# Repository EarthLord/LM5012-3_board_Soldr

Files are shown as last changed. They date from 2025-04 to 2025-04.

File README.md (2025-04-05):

# LM5012/LM5013 regulator board made for Sodlr with KiCad

## Requirements of the board from Soldr
1. Ideas that are fun and satisfying to build
2. Not trash-bound – ideally something you'd enjoy using or keeping on your desk/shelf
3. Low production cost – target is $1–3 per unit
4. Beginner-friendly – something accessible, even if it’s your first time soldering

## Specs of the board
1. 12V to 100V input to 5V output
  1. Can be down to 6V input if voltage divider for under-voltage lockout is tweaked
  2. 5V output can change also if feedback voltage divider is changed
2. 2.5A maximum output with LM5012 and 3.5A maximum output with LM5013
3. Sub 100uA current drawn at no load
4. BoM and PCB would come to around 2 to 3 USD depending on the chip used and quantity. 

### Soldering experience
The design is made such that different component sizes and soldering gun heat levels are utilized.

1. Both through hole and surface mount components
2. All surface mount components are with larger leads for hand soldering
3. Size varies from a large inductor to 0402 capacitors and resistors for surface mount components
4. Also experience of soldering an exposed pad from the back side for the regulator

## Documentation
The design is documented in the [schematic](output/schematic.pdf). The gerber files are in the gerber folder. The renders of the board are below.
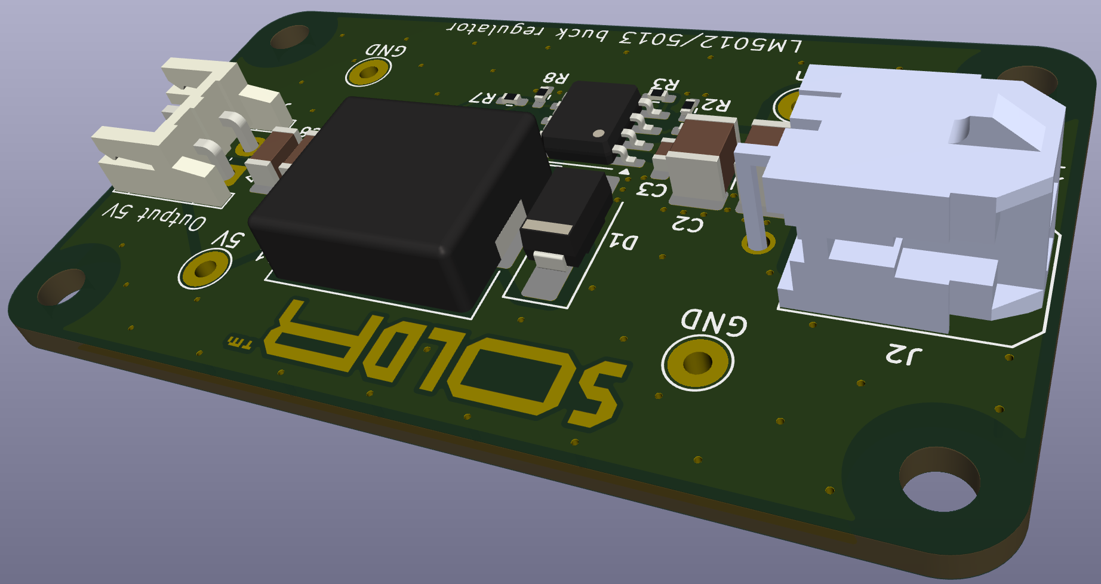
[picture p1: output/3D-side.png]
side

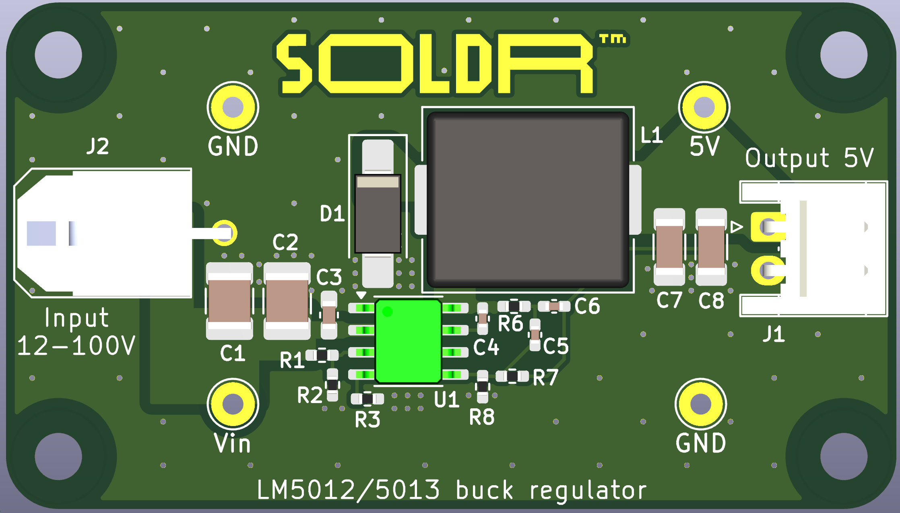
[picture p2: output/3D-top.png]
top

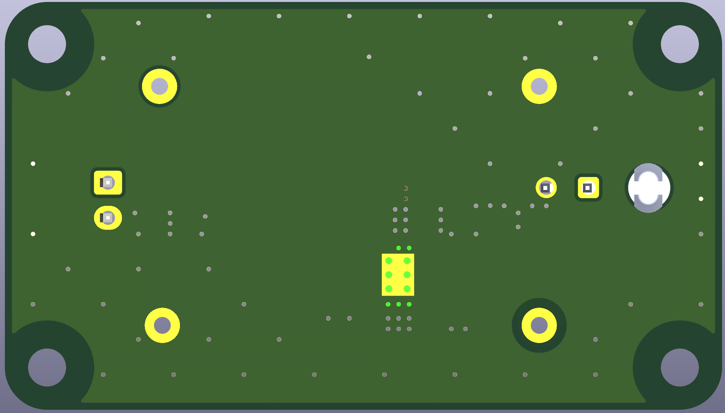
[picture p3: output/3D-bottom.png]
bottom


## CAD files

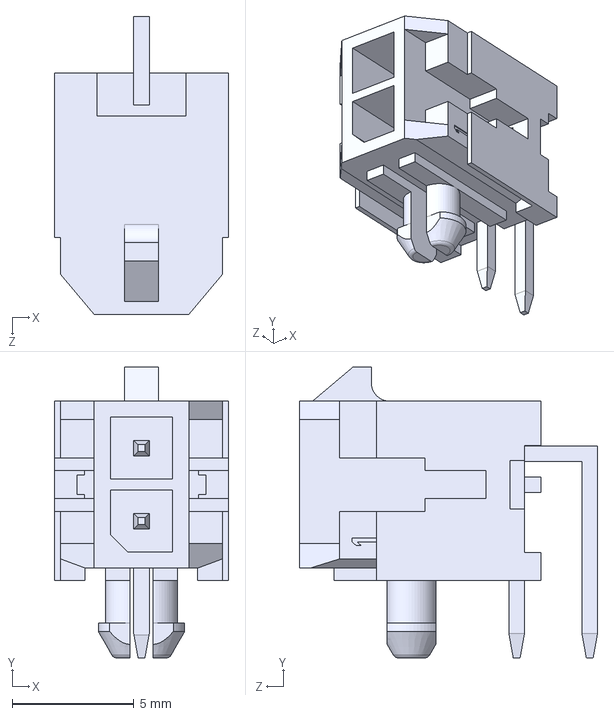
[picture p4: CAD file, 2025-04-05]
3D_models/430450200--3DModel-STEP-56544.STEP
7.15 x 11.9 x 12.2 mm

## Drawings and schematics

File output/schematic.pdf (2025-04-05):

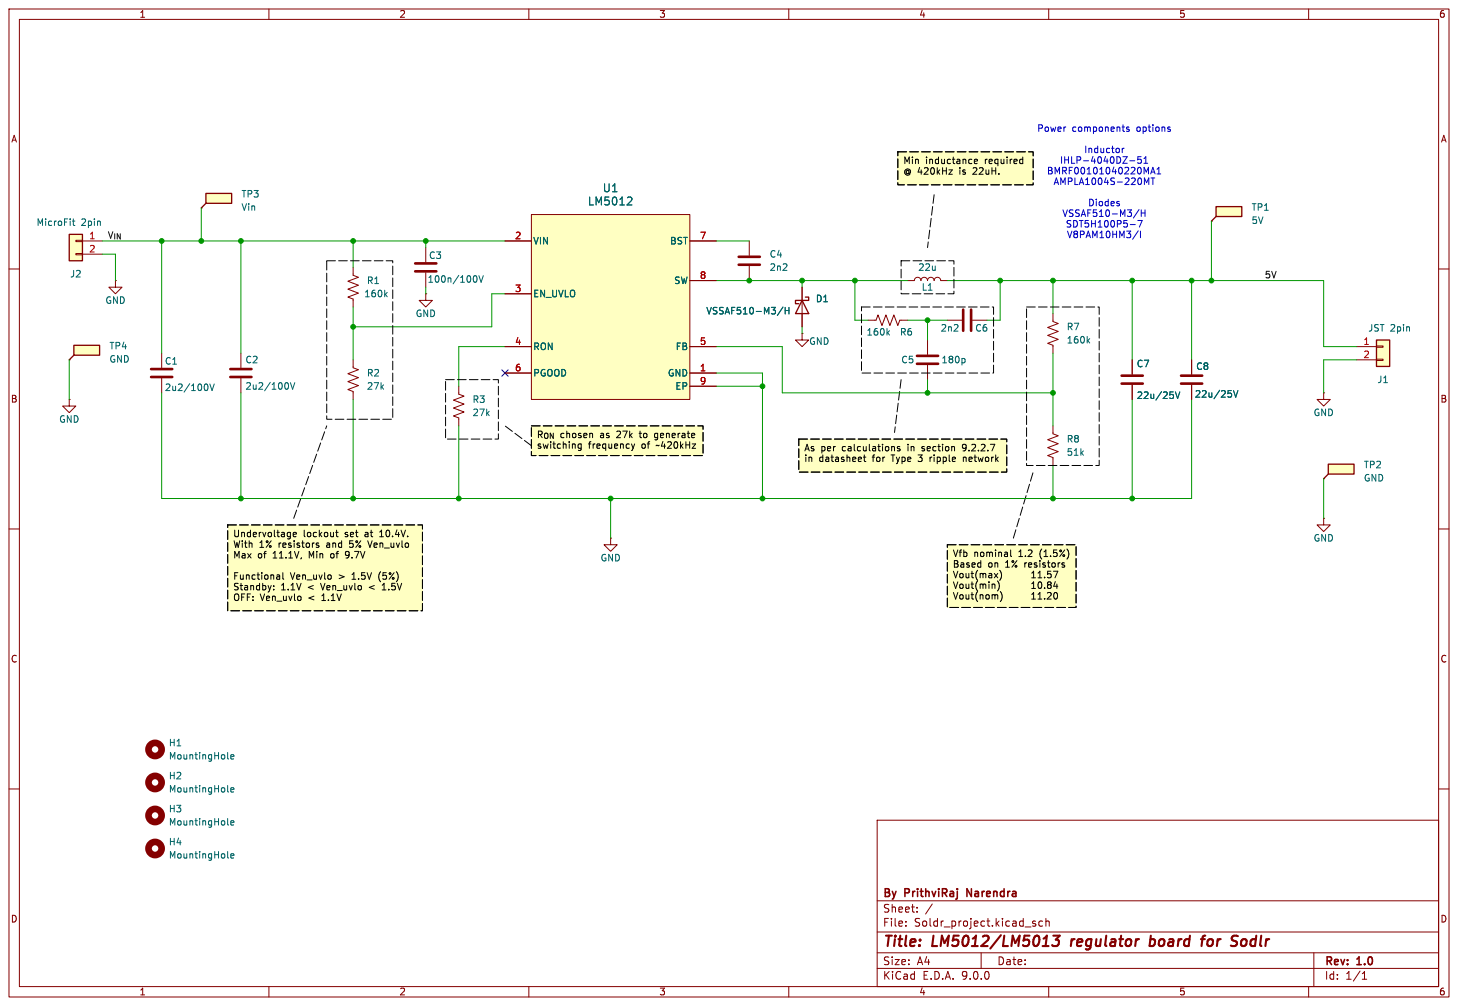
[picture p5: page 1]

160k H4 MountingHole H1 MountingHole H3 MountingHole H2 MountingHole

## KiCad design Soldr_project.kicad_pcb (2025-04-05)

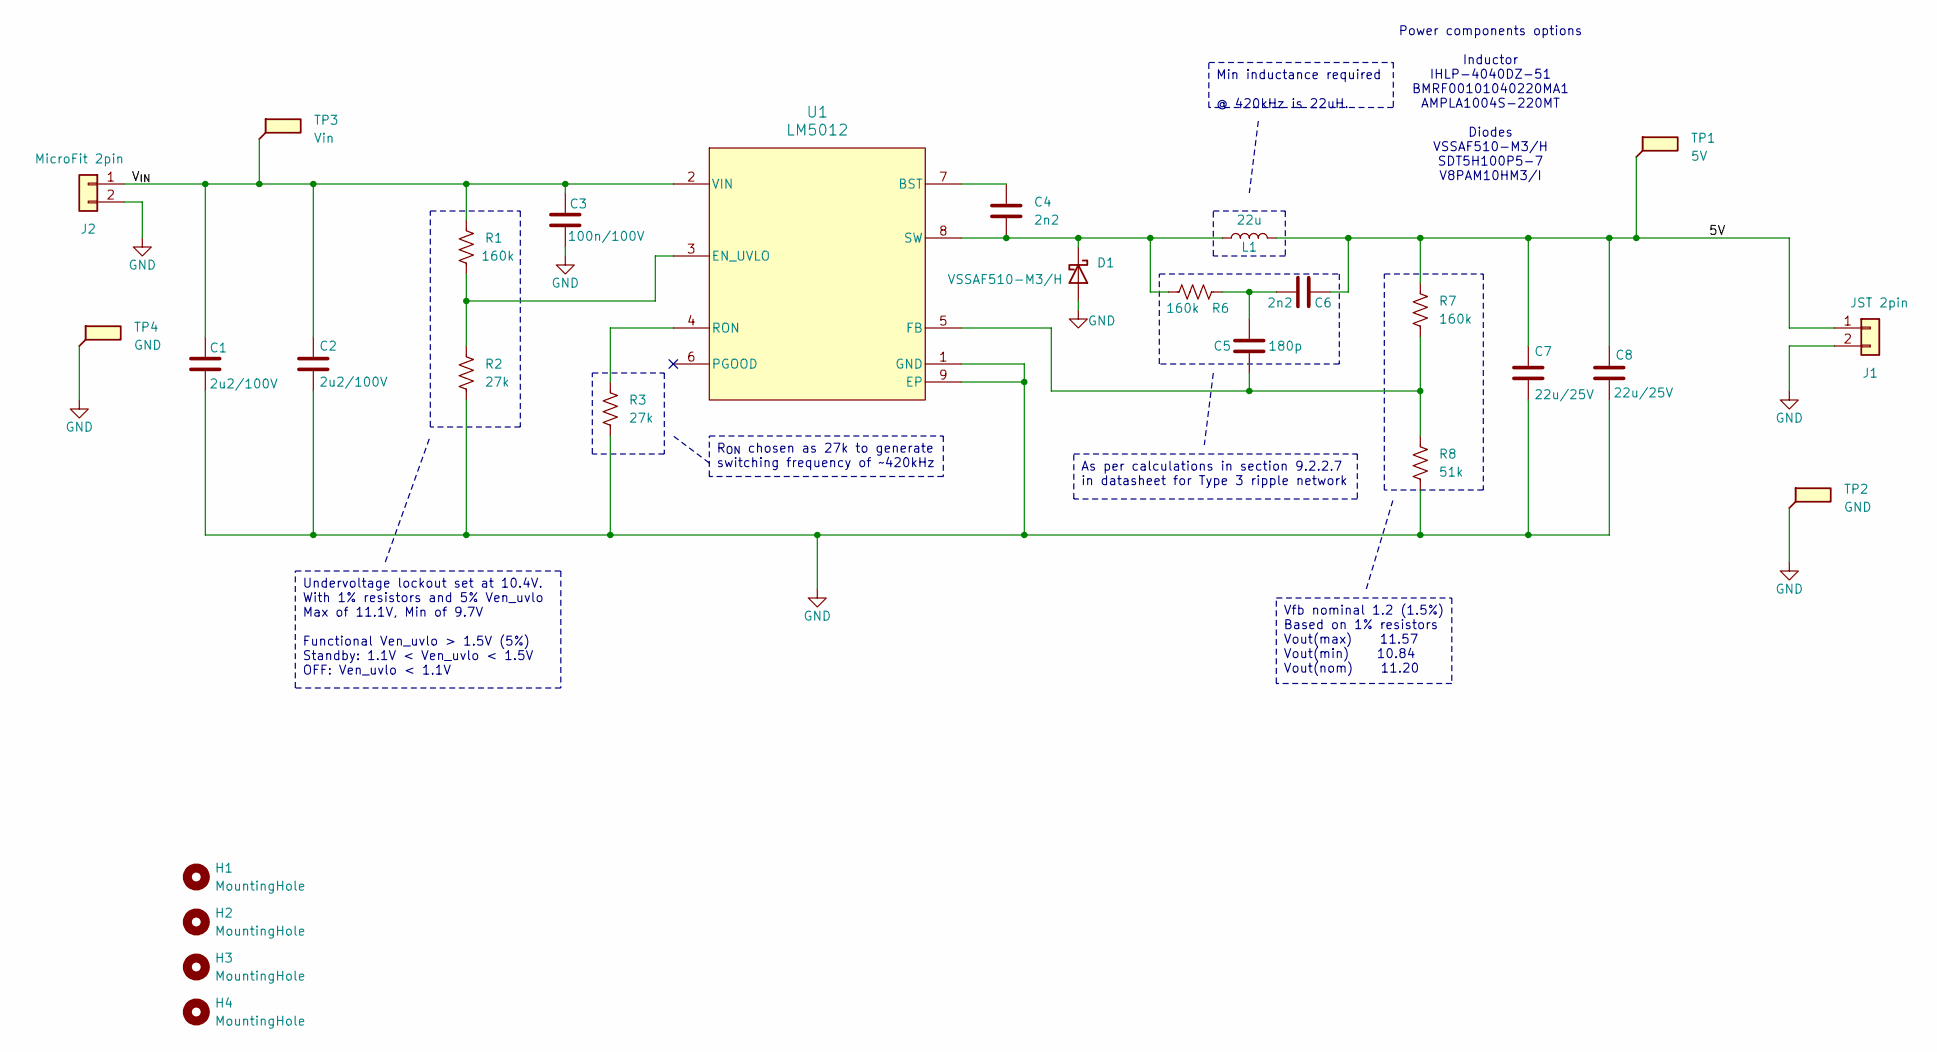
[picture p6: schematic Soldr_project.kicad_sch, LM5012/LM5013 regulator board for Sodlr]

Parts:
C1, C2: 2u2/100V; C_1210_3225Metric_Pad1.33x2.70mm_HandSolder
C3: 100n/100V; C_0603_1608Metric_Pad1.08x0.95mm_HandSolder
C4, C6: 2n2; C_0402_1005Metric_Pad0.74x0.62mm_HandSolder
C5: 180p; C_0402_1005Metric_Pad0.74x0.62mm_HandSolder
C7, C8: 22u/25V; C_1206_3216Metric_Pad1.33x1.80mm_HandSolder
D1: VSSAF510-M3/H; D_SMA_Handsoldering
H1, H2, H3, H4: MountingHole; MountingHole_2.7mm_M2.5
J1: JST 2pin; JST_EH_S2B-EH_1x02_P2.50mm_Horizontal
J2: MicroFit 2pin; Molex_Micro-Fit_3.0_43045-0200_2x01_P3.00mm_Horizontal
L1: 22u; L_Chilisin_BMRF00101040
R1, R6, R7: 160k; R_0402_1005Metric_Pad0.72x0.64mm_HandSolder
R2, R3: 27k; R_0402_1005Metric_Pad0.72x0.64mm_HandSolder
R8: 51k; R_0402_1005Metric_Pad0.72x0.64mm_HandSolder
TP1: 5V; TestPoint_THTPad_D2.5mm_Drill1.2mm
TP2, TP4: GND; TestPoint_THTPad_D2.5mm_Drill1.2mm
TP3: Vin; TestPoint_THTPad_D2.5mm_Drill1.2mm
U1: LM5012; SOIC-8-1EP_3.9x4.9mm_P1.27mm_EP2.29x3mm_ThermalVias

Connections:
/5V: C6.2, C7.1, C8.1, J1.1, L1.2, R7.1, TP1.1
/V_{IN}: C1.1, C2.1, C3.1, J2.1, R1.1, TP3.1, U1.2 (VIN)
GND: C1.2, C2.2, C3.2, C7.2, C8.2, D1.2 (A), J1.2, J2.2, R2.2, R3.2, R8.2, TP2.1, TP4.1, U1.1 (GND), U1.9 (EP)
unnamed: C5.2, C6.1, R6.2
unnamed: C4.2, D1.1 (K), L1.1, R6.1, U1.8 (SW)
unnamed: C4.1, U1.7 (BST)
unnamed: R1.2, R2.1, U1.3 (EN_UVLO)
unnamed: C5.1, R7.2, R8.1, U1.5 (FB)
unnamed: R3.1, U1.4 (RON)

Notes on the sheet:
Power components options Inductor IHLP-4040DZ-51 BMRF00101040220MA1 AMPLA1004S-220MT Diodes VSSAF510-M3/H SDT5H100P5-7 V8PAM10HM3/I
Min inductance required @ 420kHz is 22uH.
As per calculations in section 9.2.2.7 in datasheet for Type 3 ripple network
Vfb nominal 1.2 (1.5%) Based on 1% resistors Vout(max) 11.57 Vout(min) 10.84 Vout(nom) 11.20
Undervoltage lockout set at 10.4V. With 1% resistors and 5% Ven_uvlo Max of 11.1V, Min of 9.7V Functional Ven_uvlo > 1.5V (5%) Standby: 1.1V < Ven_uvlo < 1.5V OFF: Ven_uvlo < 1.1V
R_{ON} chosen as 27k to generate switching frequency of ~420kHz

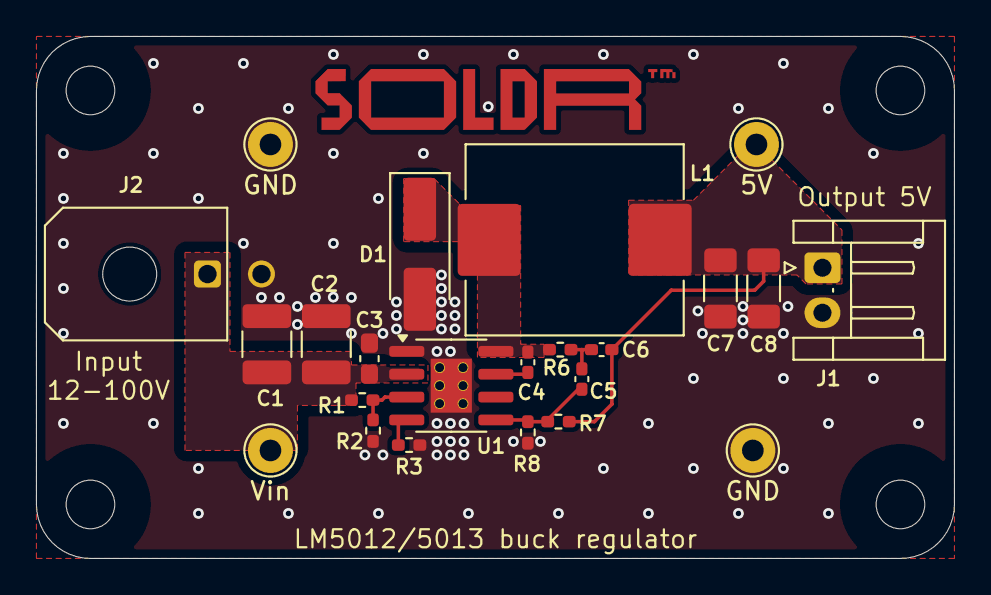
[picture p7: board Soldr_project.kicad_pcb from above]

Board: 2 copper layers, 51.0 x 29.0 mm, 27 parts (0 on the bottom side), 9 nets.

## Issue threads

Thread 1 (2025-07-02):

LM5013

QueueZob, 2025-07-02:
Hi, i'm currently working on LM5013 implementation and I've just found your project !

I would like to know how to implement your project but for the LM5013 and not the LM5012, with a required output voltage of +12V (3.5A) and input voltage of +48V.

I made previous versions myself by met few problems, and I was upset to copy/paste the exact .pcb than the LM5013-Q1 EVM test card...

I thought your solution was way cheaper and easier to make !

Could you help me to update you kicad file for the 5013 implementation, and ensure me it will work up to 3A ?

Thanks a lot

EarthLord, 2025-07-02:
Thanks!
The design would work for LM5013 as well since they are pin compatible and the thermals for this design are decent. Change the output voltage by changing the feedback resistors R7 and R8. In any case check you design in TI's Power Designer Webbench
https://webench.ti.com/power-designer/switching-regulator/customize/39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

QueueZob, 2025-07-02:
Ok thanks a lot, i also would like to know if we can keep the ON/OFF
function, I mean by putting the uvlo at the GND

Le mer. 2 juil. 2025 à 15:28, Prithvi Raj Narendra ***@***.***>
a écrit :

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

--
Victor Mullot

EarthLord, 2025-07-03:
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

You can use a 100V rated MOSFET like BSS123 to pull the EN_UVLO down like in this image

QueueZob, 2025-07-09:
> 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
>
> You can use a 100V rated MOSFET like BSS123 to pull the EN_UVLO down like in this image

After fews comparison, can you explain to me why your schematic is different than the one I downloaded from here ?
I mean i don't know which one has the correct resistances for LM5013

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

PrithviRajNarendra, 2025-07-10:
Depends on at what voltage you want to trigger UV in LM5013. Read section 8.3.9 in the datasheet https://www.ti.com/lit/ds/symlink/lm5013.pdf

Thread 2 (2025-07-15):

MOSFET Command On EN/UVLO Pin LM5012

QueueZob, 2025-07-15:
Hello, I come back to you because I have few questions :

- On your Mosfet method you have a R1 resistance, which is '10E', does it mean its 10kΩ ?

- Also, I would like to command my LM5012 or 5013 with a ON/OFF button and a Mosfet as you did, but I would like to push my button to activate the system, not to shut down it. Do you seen what I mean ? So how can I update your schematic down below ?
Thanks

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

EarthLord, 2025-07-15:
1. https://electronics.stackexchange.com/questions/251598/what-does-it-mean-that-a-resistor-has-value-of-56e Its 10 Ohm. I guess I better shift to using R instead of E as it's more standard.
2. Multiple ways of doing this. It depends on if you need to keep power on while pressed or if a press and release powers it on. Also do you need the same button to then switch off. Best would be to come up with all the requirements and ask a LLM like Gemini or ChatGPT. Once you refine it, you can also simulate it in https://www.falstad.com/circuit/circuitjs.html

QueueZob, 2025-07-15:
> 1. https://electronics.stackexchange.com/questions/251598/what-does-it-mean-that-a-resistor-has-value-of-56e Its 10 Ohm. I guess I better shift to using R instead of E as it's more standard.
> 2. Multiple ways of doing this. It depends on if you need to keep power on while pressed or if a press and release powers it on. Also do you need the same button to then switch off. Best would be to come up with all the requirements and ask a LLM like Gemini or ChatGPT. Once you refine it, you can also simulate it in https://www.falstad.com/circuit/circuitjs.html

The idea is to have a push button which stay in position, so since my button is clicked once, the system is ON until the button is pressed again. I have a 48V battery that deliver the voltage to the EN/UVLO pin but there is not much current, near 0mA

PrithviRajNarendra, 2025-07-15:
Take some time to figure out and then ask me tomorrow if you haven't figured out.

QueueZob, 2025-09-08:
Hello ! How are you ? I've recently designed my LM5013 card, based on your project. The idea was to convert 58V to 12V with ~3A of current max available. but now, i've designed et mounted the cms components, but at the end 'vout', i've only 110mV. I found that one of my test point '12V' was linke

[Carte 48V vers 12V LM5013-2025-07-11_113828.zip](https://github.com/user-attachments/files/22203936/Carte.48V.vers.12V.LM5013-2025-07-11_113828.zip)

[Schéma Carte LM5013 Version MOSFETN.pdf](https://github.com/user-attachments/files/22203946/Schema.Carte.LM5013.Version.MOSFETN.pdf)

d with de GND, so i cut the 12V pad. But now, i still have the same problem. Could you help me ?

EarthLord, 2025-09-09:
Hello, I had a look at the schematic pdf and it looks like you don't know how to use the KiCad tool. The zip file doesn't have anything in the PCB file and the schematic is what I had made. In the pic below see that the text in blue are for description in the schematic, not connections between symbols. You need to use labels which are shown in green by default. Also the connection between NMOS1's drain to NMOS2's gate isn't properly connected. Best to 1. go through any one of the numerous KiCad tutorials and 2. use a forum like electronics stackexchange to get advice for your personal project instead of an issues section of a project.

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

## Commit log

2025-04-05 Update README.md with requirements, specs and soldering experience
2025-04-05 Add the KiCad PCB design for the board
    [430450200--3DModel-STEP-56544.STEP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]
2025-04-05 Update README.md with link to schematic and pictures of the board
2025-04-05 Update README.md with point on BoM
